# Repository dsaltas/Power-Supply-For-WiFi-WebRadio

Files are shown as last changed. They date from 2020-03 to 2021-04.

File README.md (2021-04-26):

## Power Supply For WiFi WebRadio

This is a miniature power supply with built-in Li-Ion charger for [WiFi WebRadio](https://github.com/dsaltas/WiFi-WebRadio).

It is based on [LTC3440](https://www.analog.com/en/products/ltc3440.html) chip. A Micropower Synchronous Buck-Boost DC/DC Converter.

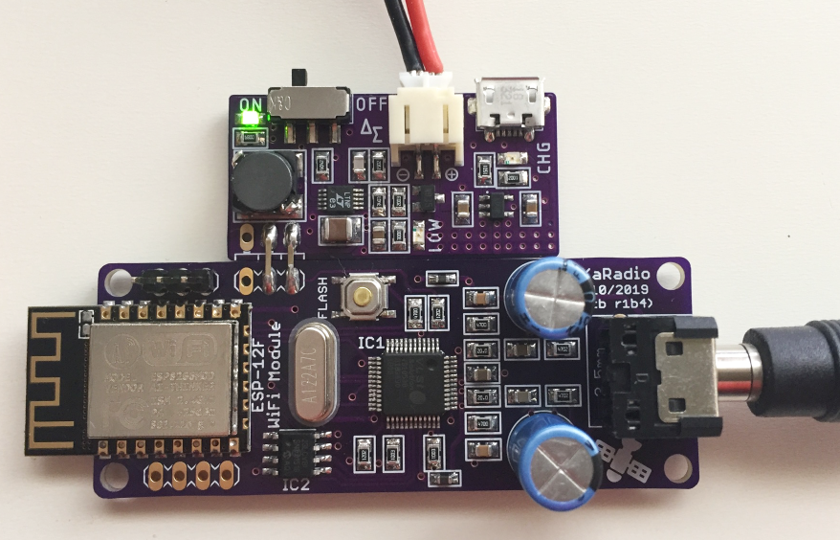
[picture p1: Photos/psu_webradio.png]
PsuWebRadio


### Features

- Voltage input 2,7V to 4,2V
- Voltage output 3,3V at 600mA
- Low battery LED indicator at 3V or less
- Li-Ion charger at 4,2V / 500mA

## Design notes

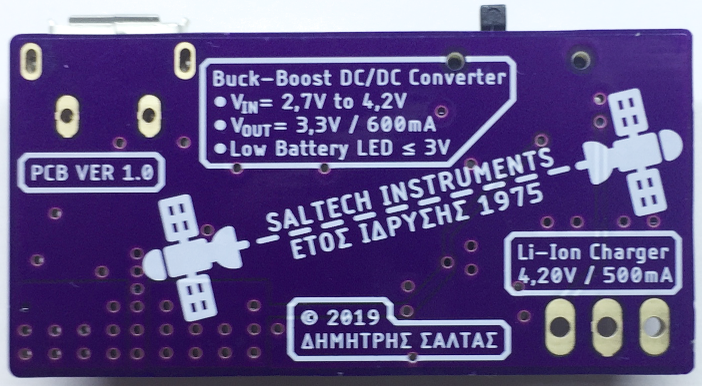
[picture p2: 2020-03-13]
Photos/bottom.png

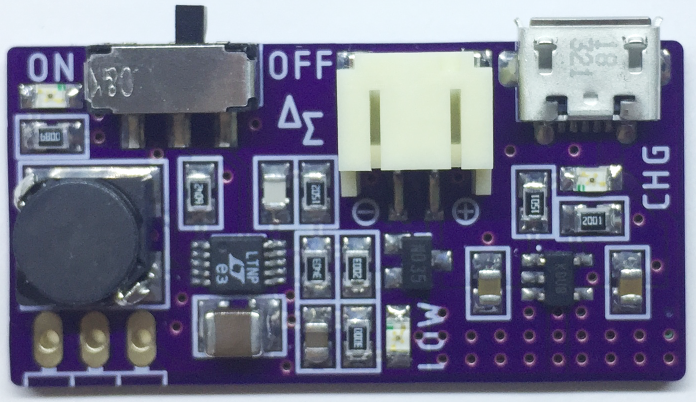
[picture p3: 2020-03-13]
Photos/top.png

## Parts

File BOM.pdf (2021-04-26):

## Power Supply For WiFi WebRadio BOM (r1B1, 2019-24-12) Project source at https://github.com/dsaltas/Power-Supply-For-WiFi-WebRadio

Qty | Part name | Package | Reference Designator | Mouser | Farnell
1 | 340KΩ 1% | 0805 | R1 | 667-ERJ-6ENF3403V
1 | 200KΩ 1% | 0805 | R2 | 667-ERJ-6ENF2003V
1 | 15KΩ 1% | 0805 | R3 | 667-ERJ-6ENF1502V
1 | 60.4KΩ 1% | 0805 | R4 | 667-ERJ-6ENF6042V
1 | 300Ω 1% | 0805 | R5 | 667-ERJ-6ENF3000V
1 | 1.5KΩ 1% | 0805 | R6 | 667-ERJ-6ENF1501V
1 | 2KΩ 1% | 0805 | R7 | 667-ERJ-6ENF2001V
1 | 680Ω 1% | 0805 | R8 | 667-ERJ-6ENF6800V
1 | 10µF 20% 6.3V X5R | 0805 | C1 | 963-JMK212BJ106MG-T
1 | 22µF 20% 6.3V X5R | 1210 | C2 | 963-JMK325BJ226MM-T
1 | 1500pF 5% 50V C0G | 0805 | C3 | 81-GRM2165C1H152JA01
2 | 4.7µF 10% 16V X7R | 0805 | C4, C5 | 81-GRM21BR71C475KE1L
1 | 10µH 30% 2A | 7mm x 7mm | L1 | 851-CDRH6D38NP-100NC
1 | LTC3440 | MSOP-10 | U1 | 584-LTC3440EMS#PBF
1 | TC54VN30CB | SOT-23A-3 | U2 | 579-TC54VN3002ECB713
1 | MCP73831T-2ACI/OT | SOT-23-5 | U3 | 579-MCP73831T-2ACIOT
1 | Yellow LED 2mA CHARGE | 0805 | LED1 | 749-SM0805YCL
1 | Red LED 2mA LOW BATT | 0805 | LED2 | 749-SM0805HCL
1 | Green LED 2mA POWER | 0805 | LED3 | 749-SM0805GCL
1 | Switch JS102011SAQN | SMD/SMT | SW1 | 611-JS102011SAQN
1 | Micro-USB AB Receptacle | SMD/SMT | J1 | 538-47589-0001
1 | JST PH Connector 2pin | SMD/SMT | J2 | S2B-PH-SM4-TB(LF)(SN) | 9492615

1

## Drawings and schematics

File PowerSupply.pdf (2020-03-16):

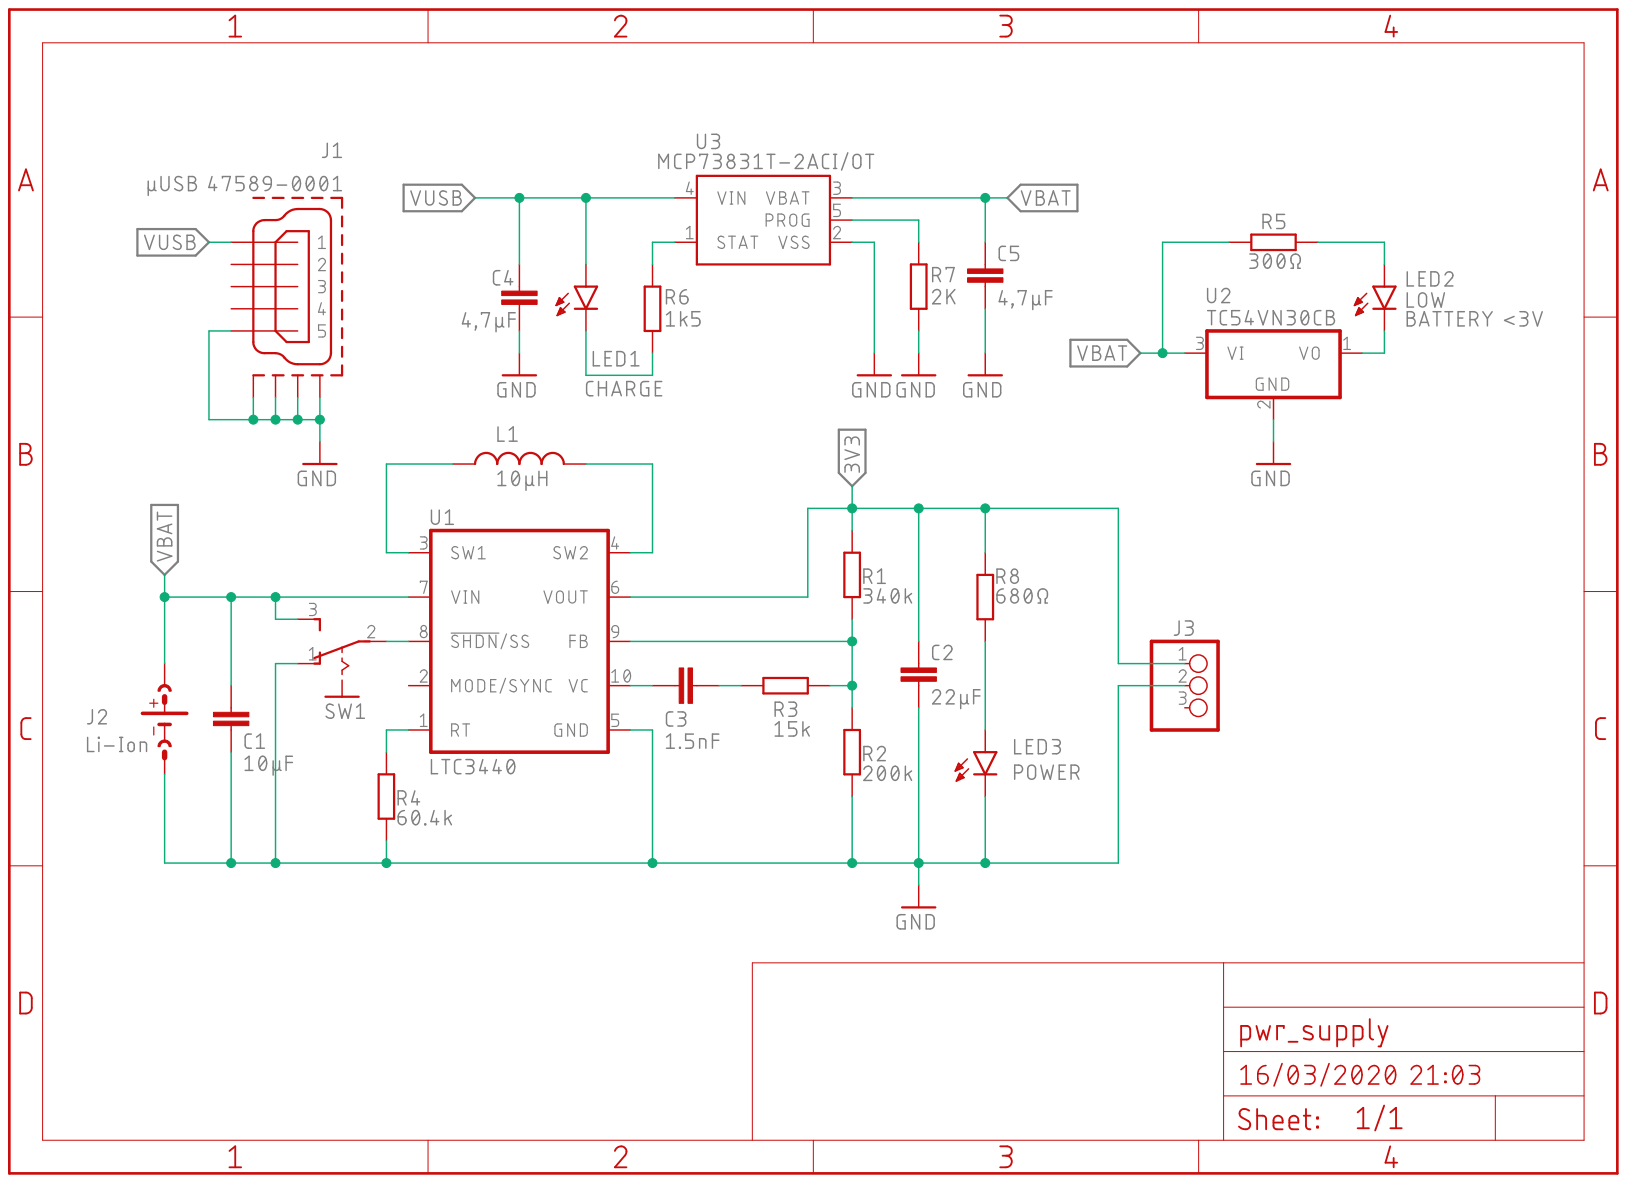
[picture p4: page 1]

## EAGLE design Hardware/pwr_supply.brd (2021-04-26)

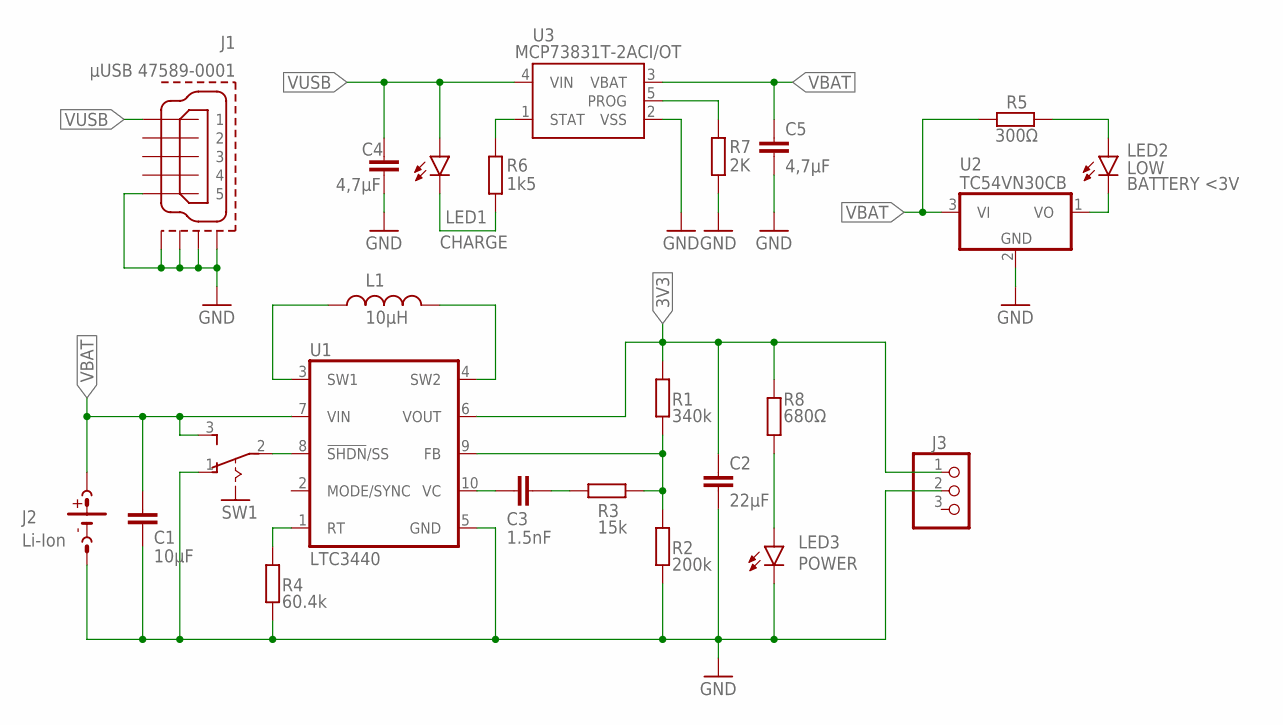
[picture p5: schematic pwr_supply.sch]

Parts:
C1: 10μF; C0805
C2: 22μF; C1210
C3: 1.5nF; C0805
C4, C5: 4,7μF; C0805
J1: μUSB 47589-0001; 47589-0001
J2: Li-Ion; JSTPH2
J3: PINHD-1X3/90; 1X03/90
L1: 10μH; CDRH6D38
LED1: CHARGE; CHIPLED_0805
LED2: LOW; CHIPLED_0805
LED3: POWER; CHIPLED_0805
R1: 340k; R0805
R2: 200k; R0805
R3: 15k; R0805
R4: 60.4k; R0805
R5: 300Ω; R0805
R6: 1k5; R0805
R7: 2K; R0805
R8: 680Ω; R0805
SW1: JS102011SAQN
U1: LTC3440; MSOP10
U2: TC54VN30CB; SOT23
U3: MCP73831T-2ACI/OT; SOT23-5

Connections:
3V3: C2.1, J3.1, R1.2, R8.2, U1.6 (VOUT)
GND: C1.2, C2.2, C4.2, C5.2, J1.5, J1.CASING1 (GND1), J1.CASING2 (GND2), J1.CASING3 (GND3), J1.CASING4 (GND4), J2.1 (-), J3.2, LED3.C, R2.1, R4.1, R7.1, SW1.1 (O), U1.5 (GND), U2.2 (GND), U3.2 (VSS)
unnamed: R4.2, U1.1 (RT)
unnamed: LED2.A, R5.1
unnamed: L1.1, U1.3 (SW1)
unnamed: L1.2, U1.4 (SW2)
unnamed: C3.1, U1.10 (VC)
unnamed: C3.2, R3.1
unnamed: R1.1, R2.2, R3.2, U1.9 (FB)
unnamed: SW1.2, U1.8 (!SHDN!/SS)
unnamed: LED2.C, U2.1 (VO)
unnamed: R7.2, U3.5 (PROG)
unnamed: R6.2, U3.1 (STAT)
unnamed: LED1.C, R6.1
unnamed: LED3.A, R8.1
VBAT: C1.1, C5.1, J2.2 (+), R5.2, SW1.3 (S), U1.7 (VIN), U2.3 (VI), U3.3 (VBAT)
VUSB: C4.1, J1.1, LED1.A, U3.4 (VIN)

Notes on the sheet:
BATTERY <3V

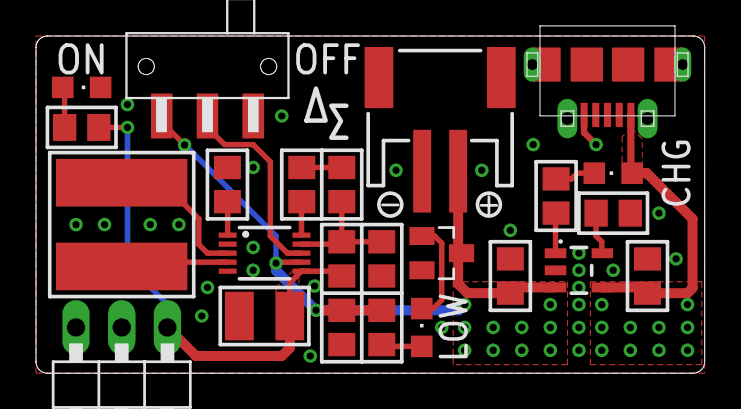
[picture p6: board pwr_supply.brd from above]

Board: 2 copper layers, 37.1 x 18.7 mm, 24 parts (0 on the bottom side), 17 nets.

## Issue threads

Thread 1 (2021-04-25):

Replace for tc54vn30cb

arlaor, 2021-04-25:
Hi @dsaltas
What other chip can I use to replace the TC54VN30CB?

dsaltas, 2021-04-25:
Hi,
By a quick lookup it seems that STM1061N30WX6F will do the job but you have to test it yourself.
Why you want to change it? TC54VN3002ECB713 is widely available.

arlaor, 2021-04-25:
Hi @dsaltas
I want to change it because I have not obtained it in my country, nor have I found a store that sends it to Colombia and that the shipping cost is not so high.Do you know a virtual store that has shipments anywhere?

arlaor, 2021-04-26:
Hi @dsaltas
Gerber and bom files is it possible for you to publish them?

dsaltas, 2021-04-26:
> Hi @dsaltas
> I want to change it because I have not obtained it in my country, nor have I found a store that sends it to Colombia and that the shipping cost is not so high.Do you know a virtual store that has shipments anywhere?

I mostly buy components from big suppliers like mouser, farnell and tme.eu.

dsaltas, 2021-04-26:
> Hi @dsaltas
> Gerber and bom files is it possible for you to publish them?

I will.

arlaor, 2021-04-26:
Hi @dsaltas
Eagle files or brd file please

dsaltas, 2021-04-26:
All done.

arlaor, 2021-05-19:
Hi @dsaltas
Since the LTC3440 chip has a support input from 2.5V to 5.5V, can I use this project power supply connected directly to a 5V phone charger, to power the karadio project, without having a battery connected?
Or this circuit only works through the use of battery and the USB connector only serves to charge the battery and not to directly power Karadio?

dsaltas, 2021-05-19:
If you want to use 5V from a charger then there is no need to use this power supply for your WiFiRadio. Just feed the 5V directly to the 5V input of WiFiRadio.
I made this little power supply specifically for battery usage. It creates a stable 3,3V from a wide voltage range that a typical lithium battery has. When is fully charged it's voltage is 4,2V and when it's empty it drops to 2,8-3,0V but the output remains at 3,3V.
Cheers

arlaor, 2021-05-19:
Hi @dsaltas

The idea is to be able to use it in both ways, one way to supply power from the usb connector when a battery is not connected and way 2 to supply power from the battery, when it is connected

dsaltas, 2021-05-20:
Ok, I get it now.
Without the battery connected the series combination of charger controller and buck-boost converter will be unstable.
You can still use MCP73831/2 controller for doing this but you need a load sharing circuit.
Here is a link with more info on how to do this:
https://blog.zakkemble.net/a-lithium-battery-charger-with-load-sharing/
Hope thaty helps!

Cheers

arlaor, 2021-05-22:
Hi @dsaltas
I try. Thanks

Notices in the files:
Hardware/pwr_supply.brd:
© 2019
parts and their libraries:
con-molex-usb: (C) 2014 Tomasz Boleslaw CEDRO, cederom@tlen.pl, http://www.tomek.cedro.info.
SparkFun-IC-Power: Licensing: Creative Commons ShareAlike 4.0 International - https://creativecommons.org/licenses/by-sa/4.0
